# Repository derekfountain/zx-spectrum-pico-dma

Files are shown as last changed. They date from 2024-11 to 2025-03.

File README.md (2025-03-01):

# zx-spectrum-pico-dma

The Z80 CPU inside the ZX Spectrum is capable of DMA transfers. i.e. an external
device can take control of the buses and directly read and write the Spectrum's
memory.

To the best of my knowledge, no interface from the Spectrum's commercial era ever
took advantage of this feature, probably because it's a rather fussy thing to
work with. I wondered if it was possible for a modern microcontroller to do it.
Hence this project.

Answer: yes, it can.

# Two implementations

My first attempt at getting this DMA idea to work used my ZX Diagnostics Board
as a test platform. The fundamental problem is that an RP2040-based Pico doesn't
have enough GPIOs to do this sort of task. (It has 26, the Z80's address and data
buses immediately account for 24 of them.) I got it to work, but synchronising
the dual Picos was too slow and fussy. I eventually gave up on that and designed
a new Spectrum interface based on the RP2350B microcontroller.

The dual Pico approach is documented towards the end of this page. It's probably
not of much interest to most people. The RP2350B implementation is the more
interesting one. So let's start there.

## RP2350B Implementation

My second attempt at getting this to work involved a Raspberry Pi RP2350B microcontroller,
which has 48 GPIOs. Unlike the original RP2040, this is plenty enough for this sort of
project. I used a [Pimoroni Stamp XL](https://shop.pimoroni.com/products/rp2350-stamp-xl?variant=53521688002939).

### The Hardware

I designed a board and had it made up. It looks like this:

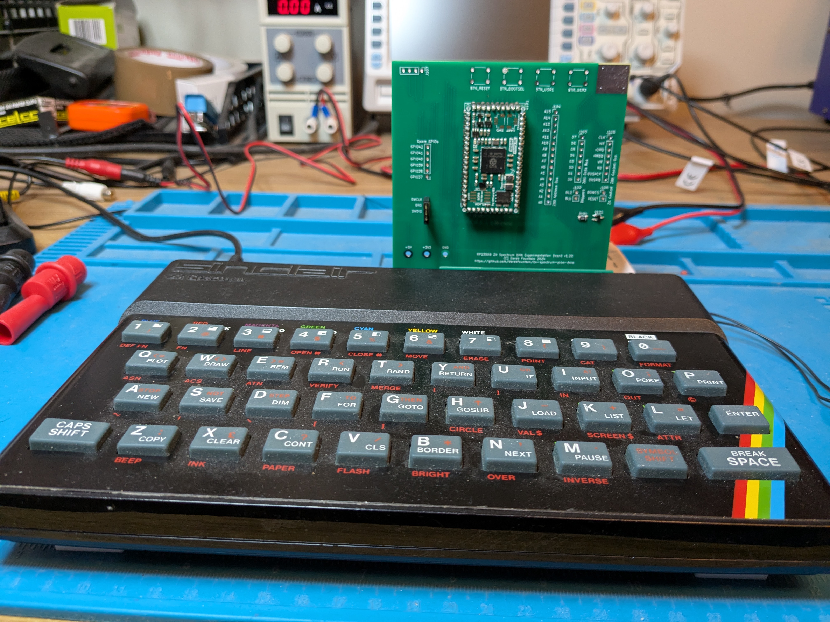
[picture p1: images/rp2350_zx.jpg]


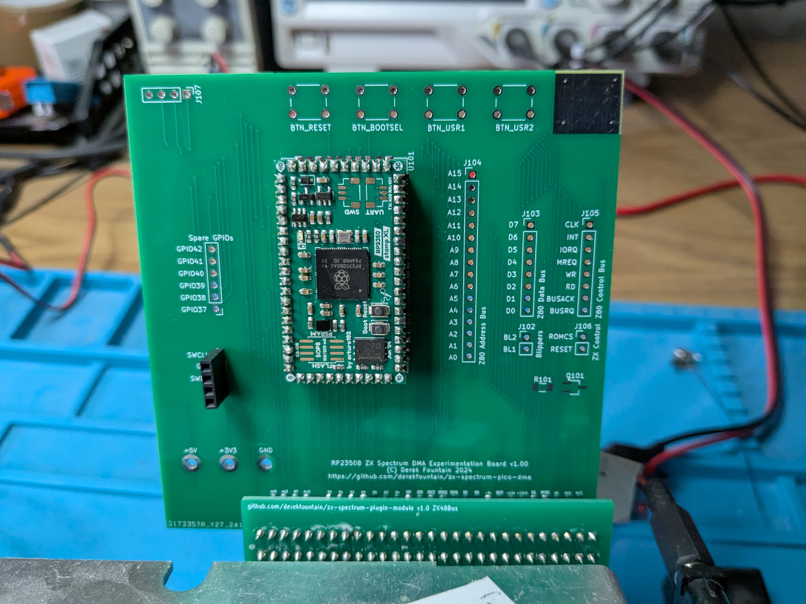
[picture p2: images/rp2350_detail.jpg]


It's very simple, the Stamp XL runs off 5V so doesn't need any extra circuitry other
than a transistor to control the Z80's RESET line.

The RP2350 can handle the Spectrum's 5V signals as direct inputs to the GPIOs, so
the design is just to link pretty much everything on the Spectrum's rear edge connector
to a GPIO pin. The rest can be done in software.

### The Contention Problem

One of the primary reasons this DMA approach has rarely, if ever, been seen on a
Spectrum interface is the contention problem. The Spectrum's display is
generated by the ULA based on data it finds in the lower 16K of RAM. In order
to do that the ULA needs to be able to read that data from the 4116 DRAM
chips. But those chips are single ported, which means if the ULA and Z80 try
to read and/or write them simultaneously contention will happen, the ULA 
will get delayed or corrupted data, and the screen display will glitch.

The solution to this in the Spectrum circuitry is to have the ULA stop the
Z80's clock while the ULA is reading the screen memory. This solution would
also be required of any circuit which uses DMA to read or write the screen
memory. That is, if an external device takes control of the buses in order
to read or write to the screen memory, that device needs to stay clear of
the ULA's screen memory accesses otherwise contention becomes a problem.

### Timings

To do a DMA transfer into screen memory (0x4000 to 0x5AFF inclusive) it needs
to be timed precisely with the Spectrum's ULA hardware. The Spectrum hardware
in this area is simple and limited. The ULA emits a signal named INT
(because it's connected to the Z80's interrupt line) every 20ms. It does so when
the hardware is about to start drawing the screen and the TV raster is at the
top left corner.

So yes, that's simple, but it's also limited, because that's the only timing
signal the Spectrum emits. I have to work with that.

### Challenge 1 - Get it working

The initial challenge, then, is to get DMA working on the Spectrum. The aim here
is to write a single byte of data into the top left corner of the screen, with
everything else remaining stable and glitch free.

I'm going to put a dotted line - value 0x55 - in location 0x4000, so 4 little
dots appear in the corner.

### Approach

The approach used for this experimentation is as follows:

* RP2350 will raise a bus request, then wait for the Z80 to yield the buses and
respond with bus acknowledge
* RP2350 will put the address 0x4000 on the address bus
* RP2350 will put the value 0x55 on the data bus
* RP2350 will drive the signal lines in sequence to force a memory write
* RP2350 will then release the bus request signal and the Z80 can go back to
doing whatever it was doing

Compared the dual-Pico approach (scroll down if you want to know) this is pretty
straightforward, and works fine.

The key point is with the timing: this is going to happen while the ULA is
drawing the top border. Contention doesn't happen when the ULA is in 
"border time", only when the ULA is drawing the data part of the screen.
So if the DMA work can be done during border time there's no need to worry
about contention.

The other question is how long the buses need to be driven for. The first version
of my software controlled the signals with the same timing the Z80 uses. It
watched the CLK signal and responded to rising and falling clocks exactly as the
Z80 does (according to the timing diagrams in the Z80 manual). But that's not
necessary. Signals on the buses and control lines (like /MREQ and /WR) get to the
4116 DRAM chips via the Spectrum's ULA and multiplexers which pass the signals
in small numbers of nanoseconds. The 4116s themselves are the slow points, being
rated at completing a read or write in 150ns. It turns out that adding a delay
of 35 RP2350 "NOP" instructions between the /WR signal going active and inactive
is the minium requirement for successful writes. On a 150MHz RP2350 35 of the
single-cycle "NOP" instructions complete in 233ns, which seems a slower than it
needs to be. I need to investigate this. My test Spectrum for this project has been
one with a static RAM-based lower memory module, so it's hard to draw conclusions
from this hardware.

### Result

There's no point is trying to do this on an emulator, so screenshots are photos
from a real Spectrum screen.

Here's the result of the single byte write:

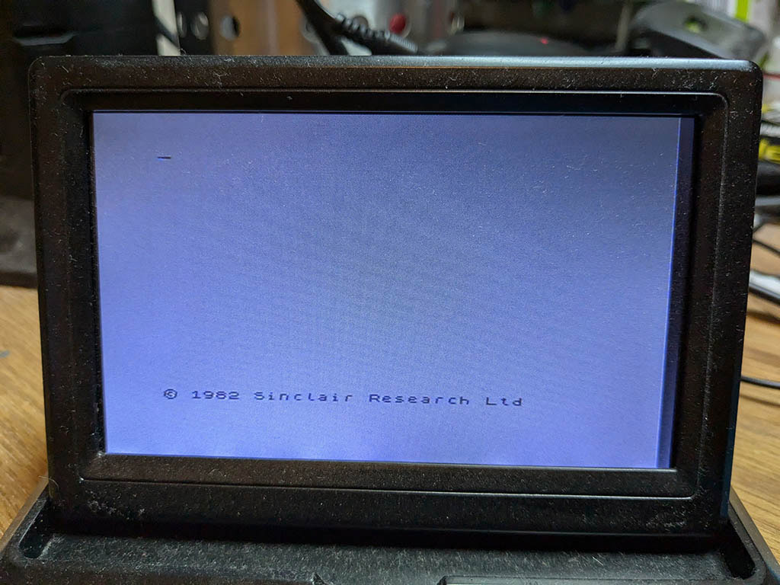
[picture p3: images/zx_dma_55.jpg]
0x55 in screen


It's fuzzy and blurry, but, take my word for it, it does show what it should:
that splat in the in the top left corner is actually 4 individual dots. It sits
there permanently. Tapping ENTER clears the screen, but the dots flicker and
reappear immediately. They're being replaced every 20ms.

There's no way to stop this from the Z80 end. The BUSREQ/BUSACK mechanism on
the Z80 is highest priority, higher than NMI, even. If I do something on the
Spectrum which disables interrupts, the dots appear there anyway. The BEEP
command still plays a note, but it's a bit "buzzy."

### Transferring a Screenful of Data

The question that needed answering here was whether the DMA transfer would be fast
enough to move a whole ZX Spectrum display frame of data (6,912 bytes) from the RP2350
into the Spectrum's display memory in the time it takes the ULA to draw the top border.
This is where the dual-Pico approach (described below) had failed, and which I needed
to work if this DMA idea was going to be useful.

I boosted the transfer from 1 byte to 6,912 bytes and looked at the timings on the
oscilloscope. It looks like this:

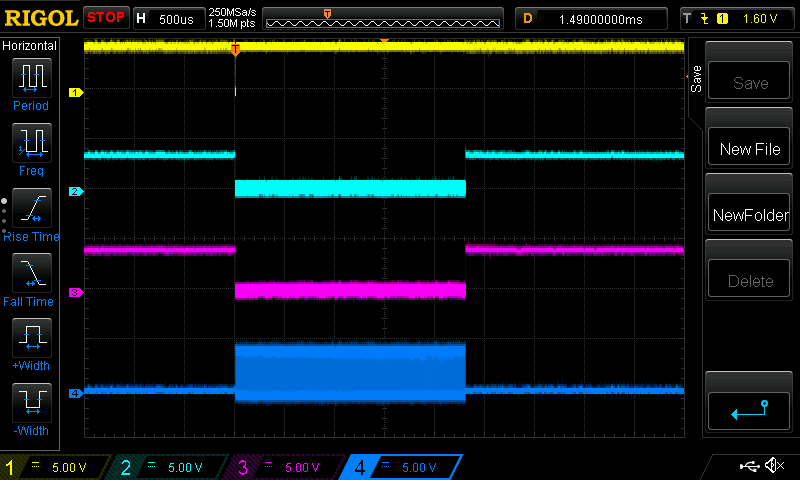
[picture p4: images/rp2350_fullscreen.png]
Full screen trace


The blip on the yellow line is the ULA's INT signal indicating a new frame is starting.
The cyan line is the BUSREQ signal as the RP2350 requests the Z80's bus, and the purple
line is the Z80's BUSACK signal showing the Z80 has yielded the bus. The dark blue line
is a test signal which the RP2350 is waggling as each of the 6,912 bytes is fed to the
Spectrum's lower memory. The entire duration of the transfer is about 2.3ms, which is
easily inside the 4.1ms the ULA takes to draw the top border.

## Success!

This is excellent news! Using the RP2350, with all its GPIOs, means it's easily possible
to DMA transfer a whole screen of data, flicker and contention free, from the 
microcontroller into the Spectrum inside the time it takes to draw the top border.

The next step will be to utilise this DMA transfer as part of a ZX co-processor. I have
this vague idea that a RP2350 can be used to do the sorts of things the ZX Spectrum finds
very hard, such as full screen scrolling. That's a different project, but in the meantime
I added a 50-frames-per-second, full screen scroll routine into the RP2350 code, just to
show it's possible. Here's a terribly wobbly (phone in one hand, typing on the rubber keys
with the other) animated GIF showing that scroll working:

Animated GIF

## ZX Diagnostics Board Implementation

**TLDR: I got DMA working via a variation of my ZX Diagnostics Board which consists
of 2 Raspberry Pi Picos. But it was slow: with one Pico controlling the address bus,
and the other Pico controlling the data and control buses, a lot of time was wasted
due to the 2 Picos needing to keep sync with one another. So although it worked, it
wasn't really a usable solution. What follows is for the enthusiastic reader only.**

My first attempt at getting this working used my [ZX Diagnostics Board](https://github.com/derekfountain/zx-spectrum-diagnostics) project
as a testbed. What follows is the write up of what I did and how far I got.
Might be useful to someone, for something.

The Pico software which was working at the end of this experimentation is
tagged as v0.2.

### The Hardware

The hardware I used for this experimentation is my [ZX Diagnostics Board](https://github.com/derekfountain/zx-spectrum-diagnostics).
This board was designed to be flexible. It exposes on headers all the signals
from the Z80 (that are on the Spectrum's rear edge connector), which makes it
ideal for this sort of hardware hackery.

The main problem with doing retro-computing projects with the Pico is the limited
number of GPIOs: 26. To interface to an 8-bit micro you need to connect
GPIOs to 16 bits of address bus and 8 bits of data bus, which is 24, plus whatever
other control bus signals you need, plus user interface buttons and other things.
26 GPIOs isn't enough.

My diagnostics board interface has 2 Raspberry Pi Picos. One Pico is set up with
GPIOs connected to the data bus and several of the Z80 control bus signals, the
other Pico is set up with GPIOs connected to the 16 bits of address bus. A bit of
to and fro is required to keep them in sync, and it isn't ideal, but it does work.

I had to modify the diagnostics board slightly because when I designed it 
BUSREQ and BUSACK where not signals I connected to either Pico. So I soldered an extra
couple of wires:

* Pico 1 GPIO 16 connected to BUSREQ
* Pico 1 GPIO 17 connected to BUSACK

These Z80 signals were also wired to Pico 2 GPIO 26 and 28 respectively.

The other signals required here are IORQ, MREQ, RD and WR. These were already
connected up to Pico 1.

### The Contention Problem

One of the primary reasons this approach has rarely, if ever, been seen on a
Spectrum interface is the contention problem. The Spectrum's display is
generated by the ULA based on data it finds in the lower 16K of RAM. In order
to do that the ULA needs to be able to read that data from the 4116 DRAM
chips. But those chips are single ported, which means if the ULA and Z80 try
to read and/or write them simultaneously contention will happen, the ULA 
will get delayed or corrupted data, and the screen display will glitch.

The solution to this in the Spectrum circuitry is to have the ULA stop the
Z80's clock while the ULA is reading the screen memory. This solution would
also be required of any circuit which uses DMA to read or write the screen
memory. That is, if an external device takes control of the buses in order
to read or write to the screen memory, that device needs to stay clear of
the ULA's screen memory accesses otherwise contention becomes a problem.

### Timings

To do a DMA transfer into screen memory (0x4000 to 0x5AFF inclusive) it needs
to be timed precisely with the Spectrum's ULA hardware. The Spectrum hardware
in this area is simple and limited. The ULA emits a signal named INT
(because it's connected to the Z80's interrupt line) every 20ms. It does so when
the hardware is about to start drawing the screen and the TV raster is at the
top left corner.

So yes, that's simple, but it's also limited, because that's the only timing
signal the Spectrum emits. I have to work with that.

### Challenge 1 - Get it working

The initial challenge, then, is to get DMA working on the Spectrum. The aim here
is to write a single byte of data into the top left corner of the screen, with
everything else remaining stable and glitch free.

I'm going to put a dotted line - value 0x55 - in location 0x4000, so 4 little
dots appear in the corner.

### Approach

The approach used for this experimentation is as follows:

* Pico1 will raise a bus request, then wait for the Z80 to yield the buses and
respond with bus acknowledge
* Pico1 will tell Pico2 - which controls the address bus - to put the address
0x4000 on the address bus
* Pico1 will put the value 0x55 on the data bus
* Pico1 will drive the signal lines in sequence to force a memory write
* When the byte is written, Pico1 will tell Pico2 to stop driving the address
bus, and will itself stop driving the data and control bus lines
* Pico1 will then release the bus request signal and the Z80 can go back to
doing whatever it was doing

The key point is with the timing: this is going to happen while the ULA is
drawing the top border. Contention doesn't happen when the ULA is in 
"border time", only when the ULA is drawing the data part of the screen.
So if the DMA work can be done during border time there's no need to worry
about contention.

The other question is how long the buses need to be driven for. The first version
of my software controlled the signals with the same timing the Z80 uses. It
watched the CLK signal and responded to rising and falling clocks exactly as the
Z80 does (according to the timing diagrams in the Z80 manual). But that's not
necessary. Signals on the buses and control lines (like /MREQ and /WR) get to the
4116 DRAM chips via the Spectrum's ULA and multiplexers which pass the signals
in small numbers of nanoseconds. The 4116s themselves are the slow points, being
rated at completing a read or write in 150ns. It turns out that adding a delay
of 19 RP2040 "NOP" instructions between the /WR signal going active and inactive
is the minium requirement for successful writes. On a 125MHz RP2040 19 of the
single-cycle "NOP" instructions complete in 152ns, which seems to add up.

### Result

There's no point is trying to do this on an emulator, so screenshots are photos
from a real Spectrum screen.

Here's the result of the single byte write:

0x55 in screen

It's fuzzy and blurry, but, take my word for it, it does show what it should:
that splat in the in the top left corner is actually 4 individual dots. It sits
there permanently. Tapping ENTER clears the screen, but the dots flicker and
reappear immediately. They're being replaced every 20ms.

There's no way to stop this from the Z80 end. The BUSREQ/BUSACK mechanism on
the Z80 is highest priority, higher than NMI, even. If I do something on the
Spectrum which disables interrupts, the dots appear there anyway. The BEEP
command still plays a note, but it's a bit "buzzy."

### Signals Analysis

Here's the trace from the oscilloscope:

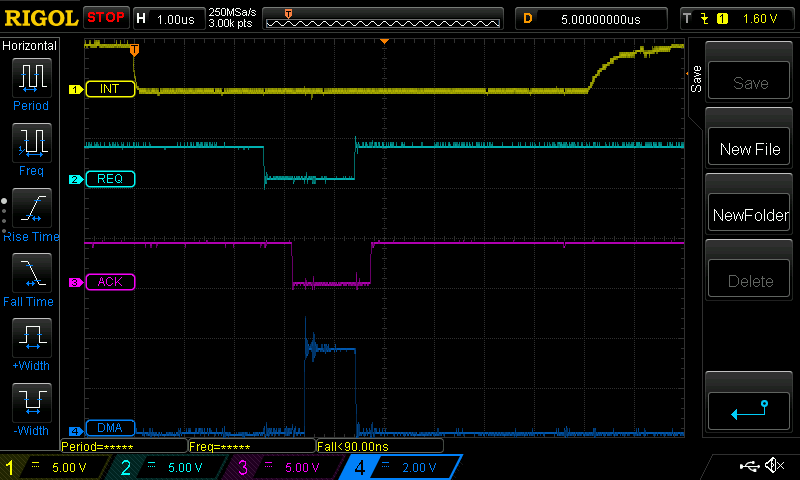
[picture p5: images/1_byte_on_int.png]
1 byte DMA trace


Yellow is the ULA's INT signal, which is pulled low every 20ms. The RP2040 on the
Pico is programmed with a hardware interrupt when that line goes low. The handler
function asserts the BUSREQ "bus request" signal, which is the light blue line.
BUSREQ goes low approximately 2.5 microseconds after INT goes low, that being the
time it takes for the RP2040 to respond to a GPIO interrupt.

The RP2040 code spins looking for BUSACK "bus acknowledge" to go low. There is a
variable length pause while the Z80 finishes the instruction it's running, and then
it pulls BUSACK low. That's the purple line. In the shown example, BUSACK goes low
about 600ns after BUSREQ went low, but this varies. The purple line flickers on
the 'scope.

When the BUSACK goes low the DMA process takes place. The dark blue line shows a high
pulse while the DMA is running. It takes just about 1uS to drive a transfer of one
byte to the Spectrum's memory. This includes the wasteful but necessary synchronisation
with the other Pico which drives the address bus.

As soon as the DMA is complete (blue line falling) the BUSREQ line is released
(light blue line rising). The Z80 retakes control (purple line rising as it turns
off the BUSACK signal) and the process is complete. End of DMA to the Z80 having
control again is about 150ns.

The Z80 "loses" the period of the purple line being low, which is about 1.6uS.

### Challenge 2 - More data

Proving a single byte can be written into Spectrum memory is gratifying, but not really
very useful. Next step is to try writing more data. Let's try 2KB. This requires
advancing the value on the address bus with each byte written. Here's the screen,
again a bit fuzzy, but correctly showing what it should:

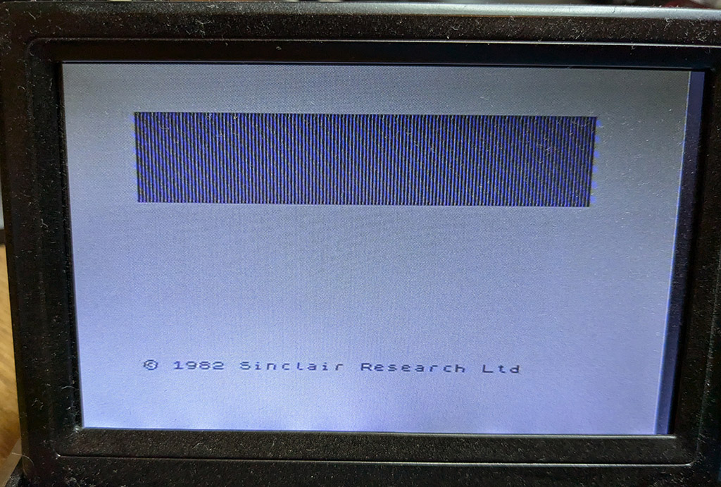
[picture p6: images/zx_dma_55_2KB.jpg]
0x55 in 2KB screen


That pattern is permanent, and since it takes a lot longer to transfer in than the
single byte example, the BEEP is a lot buzzier. Some games, presumably those that
don't read back their screen data, still work. Jetpac, for example, still runs quite
happily even though you can't see what you're doing.

The trace from the oscilloscope:

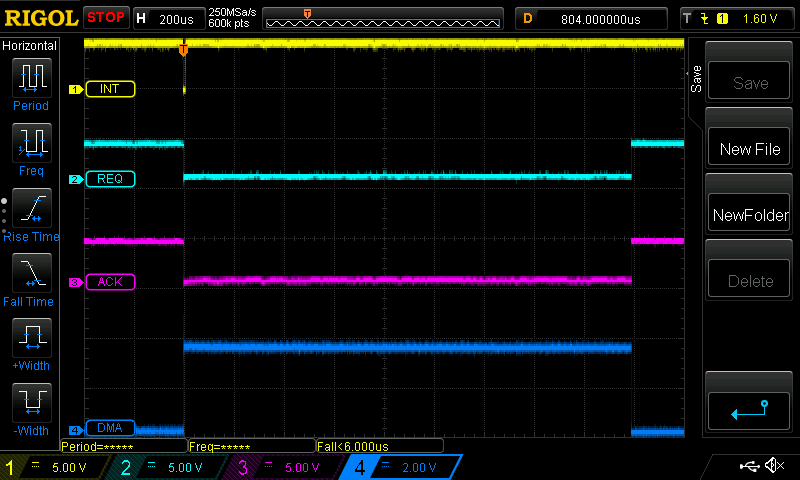
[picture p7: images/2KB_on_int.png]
2KB DMA trace


This all looks OK, but a problem is starting to appear. It takes the ULA 224 Z80 T-states
to draw a single line of the screen, and the top border is 64 lines high. So  Spectrum "top
border time" is 64 line times, which is 14,336 T states. A T is 1/3,500,000 of a second so
top border time is 0.004096 of a second, or a smidge over 4ms. The oscilloscope trace shows
the DMA time for 2048 bytes (dark blue line) to be just about 1,800uS, or 1.8ms. That's to
DMA one third of a Spectrum screen. A full screen will take 5.4ms, not including the time
taken to transfer the attributes data which is another 768 bytes (32x24 bytes).

I put a trace pulse in the code which drives the address bus:
 
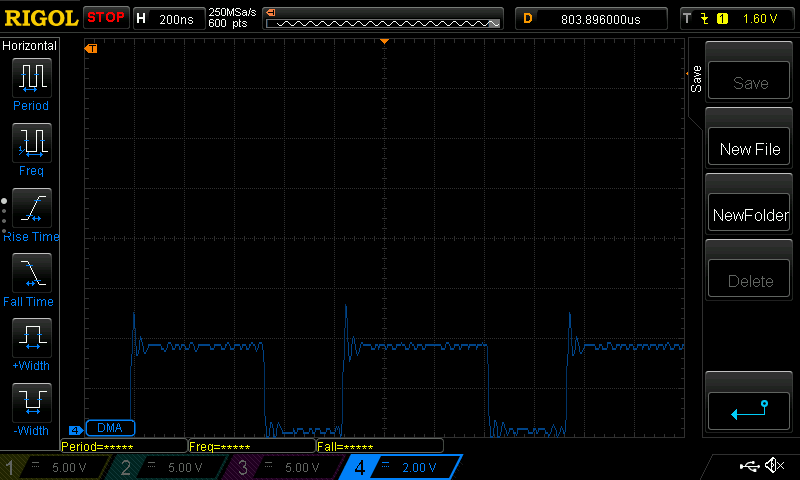
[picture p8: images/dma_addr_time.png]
Addr time trace


This line goes high at the point the required address is loaded onto the Z80's address
bus, then goes low again when the address bus is relinquished. It takes about 500ns,
so that's the time for writing one byte. On top of that, there's quite a bit of overhead as
the Picos signal and synchronise with each other, all of which could be removed if I can use a
single microcontroller with enough GPIOs to do everything itself. But I don't have one
of those, and there's no way to avoid the synchronisation at the moment.

This is disappointing. DMA can only really be done in border time, to avoid contention. (I
saw plenty of contention while I was experimenting with this. The screen glitches all over
the place.) I was hoping to be able to do full screen scrolling in the RP2040, for example,
but clearly if the screen can't be quickly transferred back into the Spectrum after processing
then it's not much use.

I figured it might be possible to interweave the DMA with the CPU's CLK signal. The CLK is
generated by the ULA, so when the CLK signal goes flat that means the ULA is accessing
RAM. But that means somehow accessing the CLK such that when it stops pulsing the RP2040
stops the DMA. It might be possible to do that? Perhaps a PIO watching the CLK signal
and indicating to the core when the CLK stops? I didn't try it but it might work.

### Challenge 3 - A Screenful

Next step is to try transferring a full screen of data into the Spectrum. This is the
underlying requirement. If an RP2040 is to be used to do full screen scrolling or other such
things it needs to be able to transfer the results back into the Spectrum at 50fps. If it
can't there's only so much point in doing it. You might as well do the job on the Spectrum.

So this next experiment does what the previous ones do: transfer a block of data into the
Spectrum at the point of the ULA's INTerrupt, when the ULA is drawing the top border. The
data block for a full screen is 6,912 byte - 6,144 for the graphics, plus 768 for the 
attributes.

Here's how the result looks:

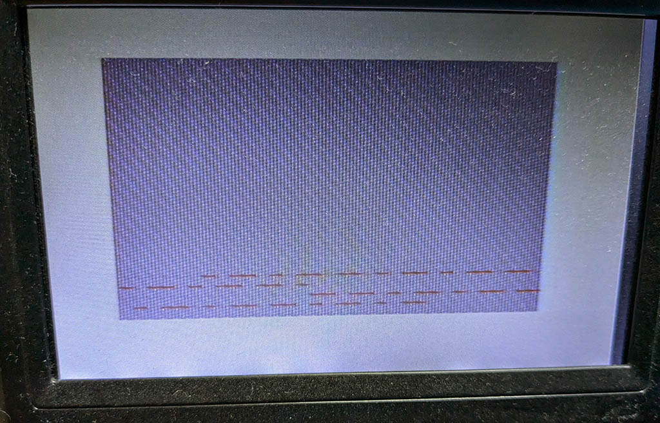
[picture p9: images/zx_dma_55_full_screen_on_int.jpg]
Full screen DMA trace


The screen fills as expected, but there's shimmering and glitching, and the Spectrum hangs.

The oscilloscope trace looks like this:

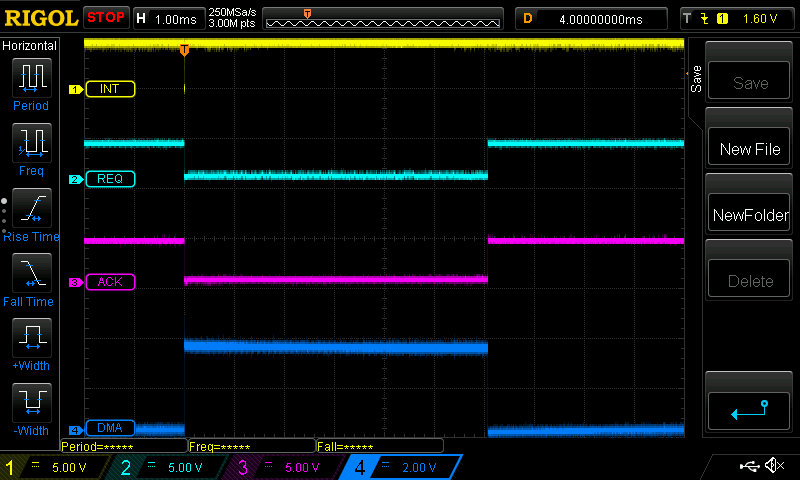
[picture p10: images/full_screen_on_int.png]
Full screen trace


This is at 1ms per division, the entire DMA trace takes just over 6ms. Top border time is
4ms, this is causing contention, hence the flickering.

I think the Spectrum is hanging because the Z80 is getting incorrect data from the lower
RAM, which is where it stores system information. The contention doesn't just affect the
screen memory, it affects all the lower 16K. I'm not entirely sure what's going on with this
hangup to be honest, but it doesn't really matter. A full screen DMA isn't possible in top
border time.

#### Try Bottom Border Time

The Spectrum's border is in two pieces, top and bottom, separated by the screen image of course.
If I can start the DMA at the point the ULA starts to draw the bottom border (i.e. just as it's
finished drawing line 192 of the screen itself) then I get bottom border time, followed by top
border time, before the ULA wants to access the RAM again (in order for it to start drawing the
top line of the screen).

Lower border is 56 lines at 224Ts per line, which is 12,544 Ts. On the 3.5MHz Z80 12,544 T-states
takes 0.003584 seconds, or 3.584ms. So if I can time it perfectly, I get 3.584ms of bottom
border time, followed by 4.096ms of top border time, to complete the DMA without causing
contention. That's 7.68ms, which should be enough to complete the full screen DMA which takes
just over 6ms.

The problem is that there's no timing signal or indication that the ULA has completed drawing the
data area and is about to start drawing the bottom border. The only option is to do it on a timer.
To hit the start of lower border time from the moment INT fires, I need 64 lines of top border,
plus 192 lines of screen, That's 228 lines from INT to the start of the lower border. At 224Ts per
line, 228 lines is 64,512 Ts. That's 18.432ms.

The approach here is to start a timer for 18,432uS in the INT handler, then go back to sleep. The
DMA actually happens when the second timer expires:

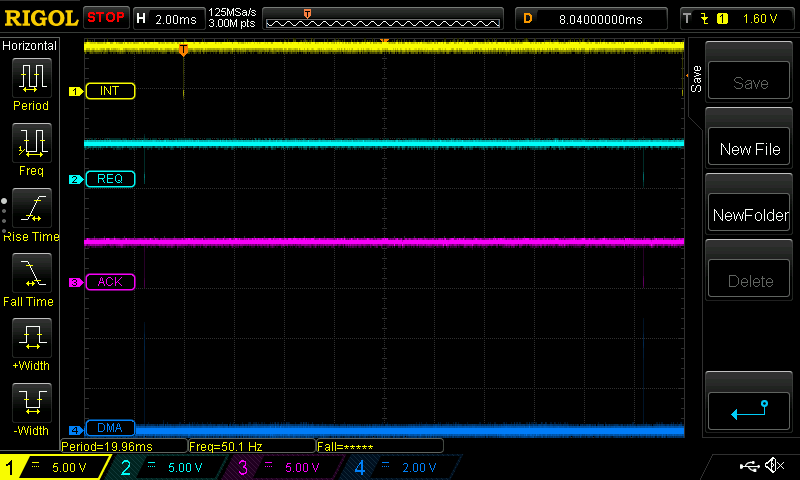
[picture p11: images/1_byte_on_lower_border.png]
1 byte on lower border trace


Here, yellow shows is the INT signal, which is the point when the 18,432uS timer is started. Light
blue shows the BUSREQ signal, which is the start of the DMA process. The 'scope's cursor shows the
time difference between the two:

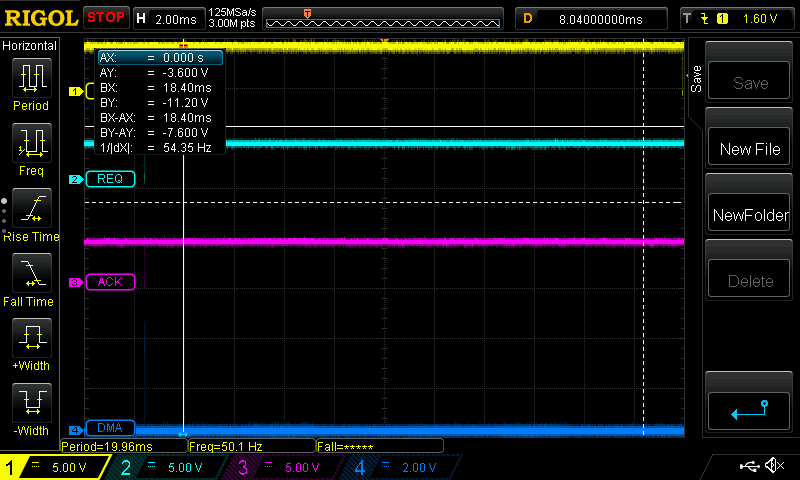
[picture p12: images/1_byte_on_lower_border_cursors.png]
1 byte on lower border trace


The gap is 18.4ms, which looks right. I'm hoping the 0.032ms offset is a measuring error.

The above images are based on a single byte DMA, which worked. But something very odd started
happening in the RP2040 when I made the transfer larger. It seems the Pico SDK wouldn't set up the
next alarm call function until the current one finished executing. So the first INT would arrive
and its handler would set the 18.4ms timer running. When that expired the DMA would start. But with
a large DMA, the transfer would still be running when the next INT arrived. With the alarm timer
still running and DMAing bytes to the Spectrum, either the INT handler didn't run, or it wouldn't
set up the alarm handler correctly. After a lot of messing about I found that doing the DMA
transfer from the second core of the RP2040 made the problem go away and the screen filled as
expected:

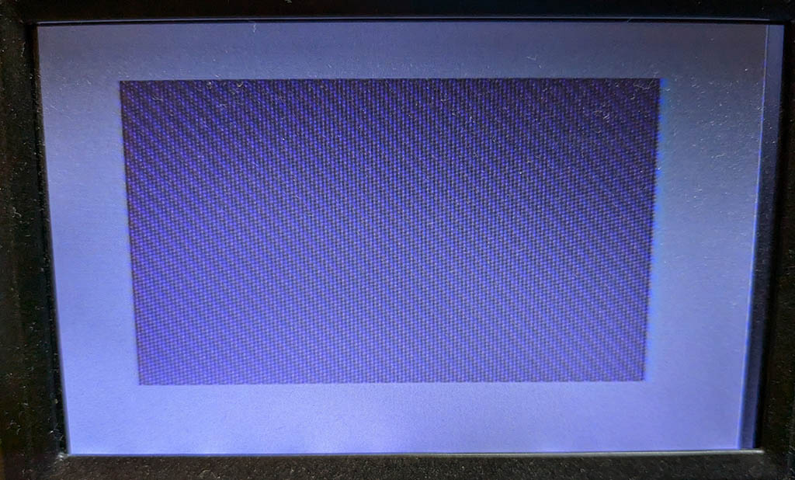
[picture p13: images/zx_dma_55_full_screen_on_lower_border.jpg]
Full screen DMA trace


Here's the oscilloscope trace:

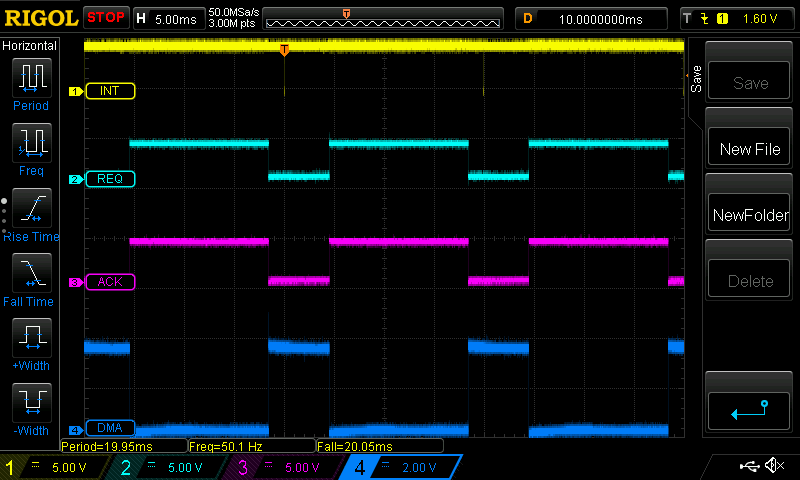
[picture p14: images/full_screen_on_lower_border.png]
full screen on lower border trace


The first INT is where the orange trigger cursor is on the yellow line. That causes a handler
to run which sets up an alarm to call the DMA function 18.4ms seconds later. The DMA function
for that INT is the next one on the light blue line - i.e. not the one directly below the INT,
but the one nearly 4 divisions later, to the right. As you can see, the next INT arrives during
the DMA process, which sets up the next alarm while the current one finishes, and so on.

## Fail

With the dual core hack in place, this worked! Hurrah! Only it didn't, because although the DMA
worked correctly, and at just about spot on 6.0ms was plenty quick enough to be inside the 7.68ms
dual borders time, the Spectrum hanged every time. It took me an age to work out why, but it's
obvious when you know: the INT signal is being generated correctly by the ULA, and the Pico is
responding to it correctly, but because the bus request is active when the next INT comes in
the Z80 (which is effectively sitting suspended) doesn't see it. So the Spectrum's not getting to
run its interrupt routine which does all sort of useful stuff like reading the keyboard.

It might still be possible to make this work. Some of the DMA transfer could be done in lower
border time, and as long as that was finished and the BUSREQ removed by the time the next INT
arrived, it might then be possible to do the rest of the DMA transfer in top border time. i.e. do it
in two portions. But for BASIC to work properly the top border transfer needs to be well clear of
the Spectrum ROM's interrupt handler routine. It's messy and fiddly and not really the solution
I'm after.

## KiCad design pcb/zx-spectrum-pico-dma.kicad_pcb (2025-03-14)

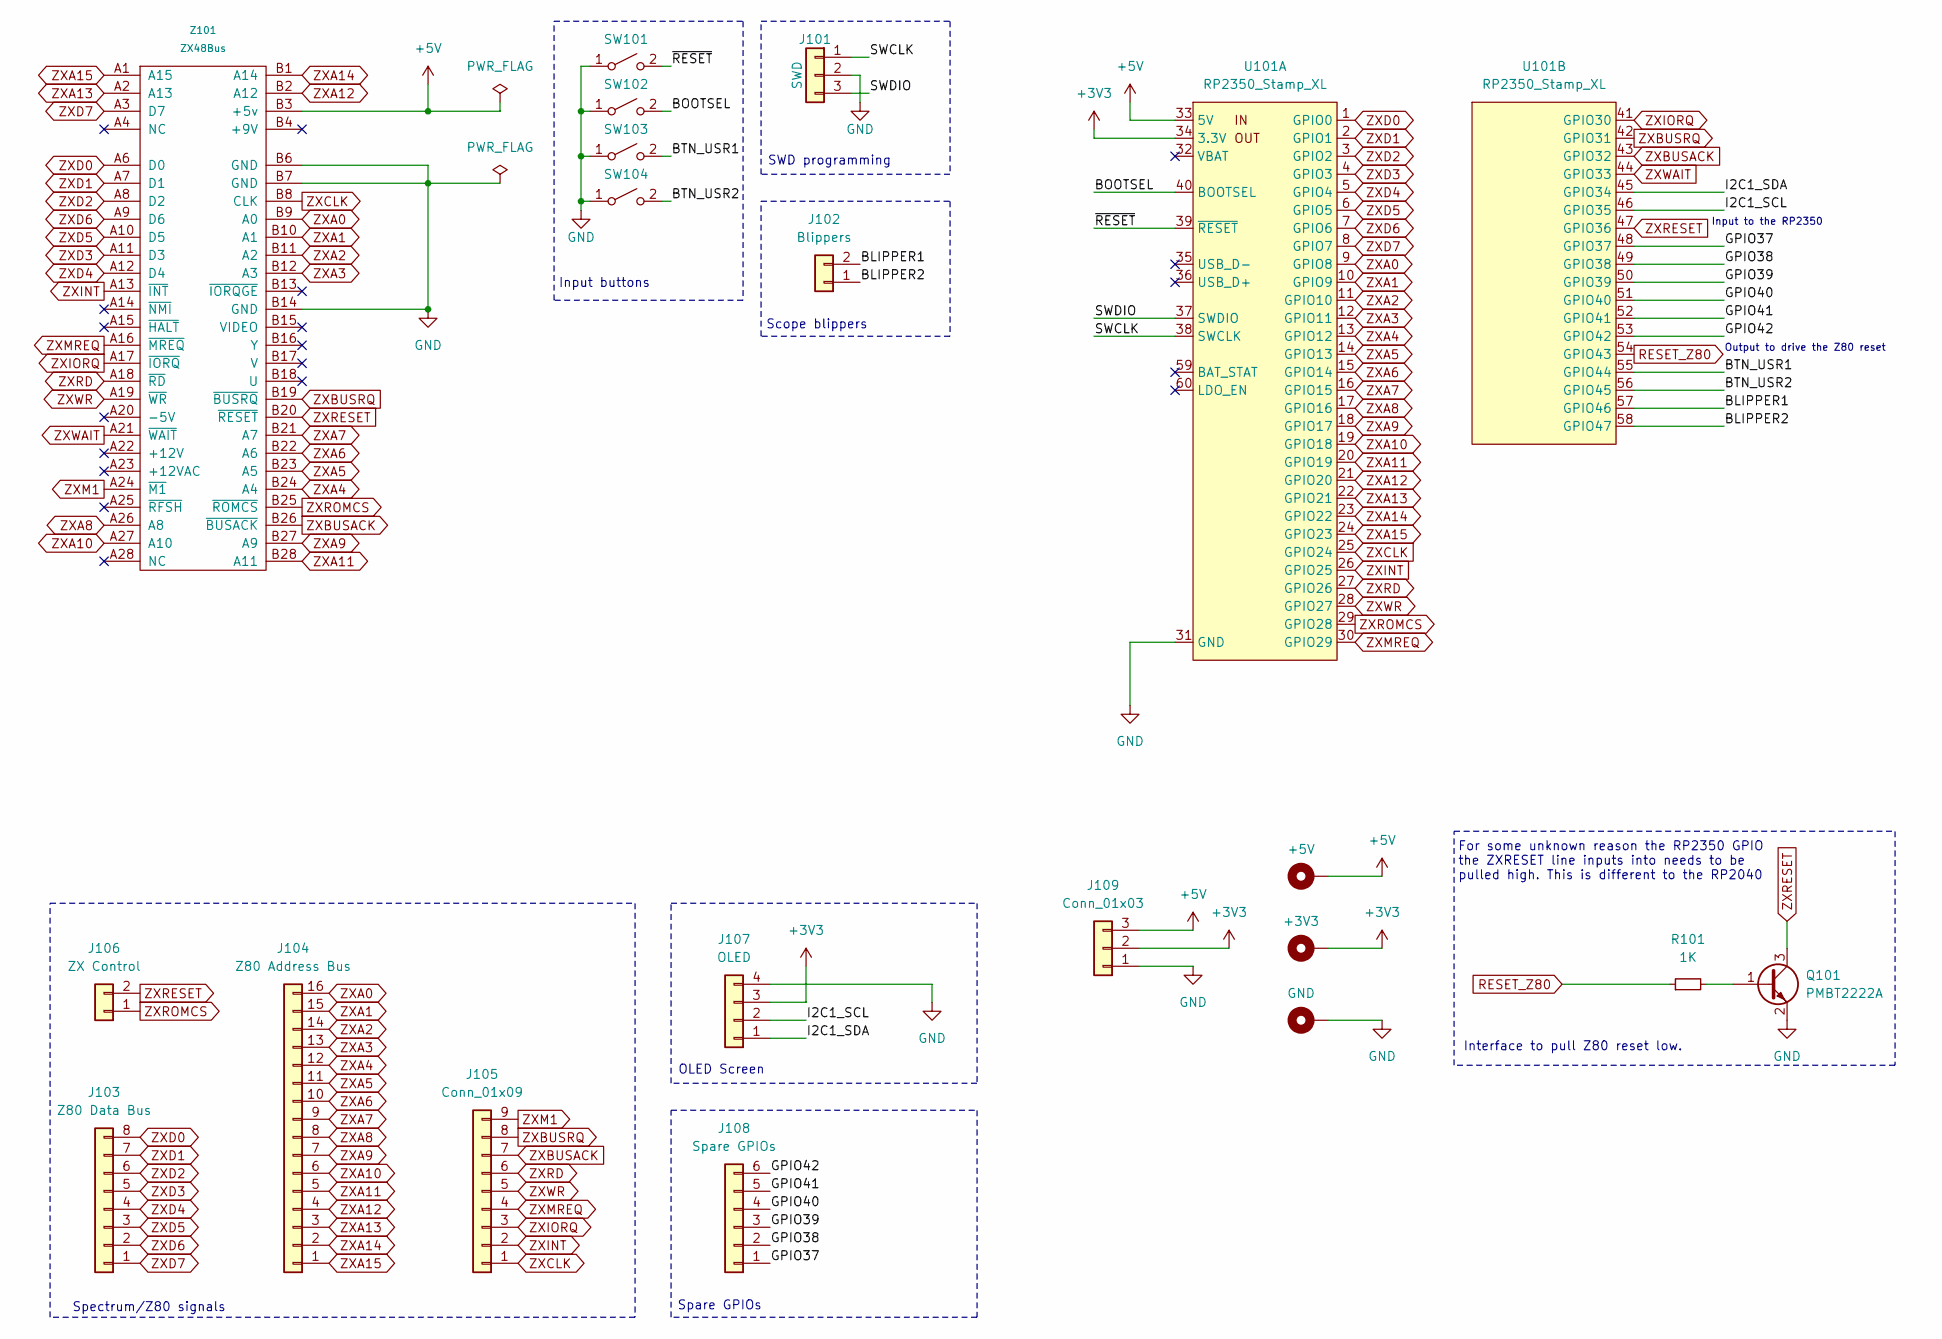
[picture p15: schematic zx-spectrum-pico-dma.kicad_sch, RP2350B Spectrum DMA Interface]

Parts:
H101: +5V; MountingHole_2.2mm_M2_Pad
H102: +3V3; MountingHole_2.2mm_M2_Pad
H103: GND; MountingHole_2.2mm_M2_Pad
J101: SWD; PinHeader_1x03_P2.54mm_Vertical; LCSC C7433424
J102: Blippers; PinHeader_1x02_P2.54mm_Vertical
J103: Z80 Data Bus; PinHeader_1x08_P2.54mm_Vertical
J104: Z80 Address Bus; PinHeader_1x16_P2.54mm_Vertical
J105: Conn_01x09; PinHeader_1x09_P2.54mm_Vertical
J106: ZX Control; PinHeader_1x02_P2.54mm_Vertical
J107: OLED; PinHeader_1x04_P2.54mm_Vertical
J108: Spare GPIOs; PinHeader_1x06_P2.54mm_Vertical
J109: Conn_01x03; PinHeader_1x03_P2.54mm_Vertical
Q101: PMBT2222A; TSOT-23_HandSoldering
R101: 1K; R_1206_3216Metric_Pad1.30x1.75mm_HandSolder
SW101: BTN_RESET; SW_PUSH_6mm_H4.3mm; LCSC C561514
SW102: BTN_BOOTSEL; SW_PUSH_6mm_H4.3mm; LCSC C561514
SW103: BTN_USR1; SW_PUSH_6mm_H4.3mm; LCSC C561514
SW104: BTN_USR2; SW_PUSH_6mm_H4.3mm; LCSC C561514
U101: RP2350_Stamp_XL; RP2xxx_Stamp_XL_THT
Z101: ZX48Bus; Spectrum_Edge_Connector

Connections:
+3V3: H102.1, J107.3, J109.2, U101.34 (3.3V)
+5V: H101.1, J109.3, U101.33 (5V), Z101.B3 (+5v)
/BLIPPER1: J102.2, U101.57 (GPIO46)
/BLIPPER2: J102.1, U101.58 (GPIO47)
/BOOTSEL: SW102.2 (B), U101.40 (BOOTSEL)
/BTN_USR1: SW103.2 (B), U101.55 (GPIO44)
/BTN_USR2: SW104.2 (B), U101.56 (GPIO45)
/GPIO37: J108.1, U101.48 (GPIO37)
/GPIO38: J108.2, U101.49 (GPIO38)
/GPIO39: J108.3, U101.50 (GPIO39)
/GPIO40: J108.4, U101.51 (GPIO40)
/GPIO41: J108.5, U101.52 (GPIO41)
/GPIO42: J108.6, U101.53 (GPIO42)
/I2C1_SCL: J107.2, U101.46 (GPIO35)
/I2C1_SDA: J107.1, U101.45 (GPIO34)
/SWCLK: J101.1, U101.38 (SWCLK)
/SWDIO: J101.3, U101.37 (SWDIO)
/~RESET: SW101.2 (B), U101.39 (~RESET)
GND: H103.1, J101.2, J107.4, J109.1, Q101.2 (E), SW101.1 (A), SW102.1 (A), SW103.1 (A), SW104.1 (A), U101.31 (GND), Z101.B6 (GND), Z101.B7 (GND), Z101.B14 (GND)
unnamed: Q101.1 (B), R101.2
RESET_Z80: R101.1, U101.54 (GPIO43)
ZXA0: J104.16, U101.9 (GPIO8), Z101.B9 (A0)
ZXA1: J104.15, U101.10 (GPIO9), Z101.B10 (A1)
ZXA2: J104.14, U101.11 (GPIO10), Z101.B11 (A2)
ZXA3: J104.13, U101.12 (GPIO11), Z101.B12 (A3)
ZXA4: J104.12, U101.13 (GPIO12), Z101.B24 (A4)
ZXA5: J104.11, U101.14 (GPIO13), Z101.B23 (A5)
ZXA6: J104.10, U101.15 (GPIO14), Z101.B22 (A6)
ZXA7: J104.9, U101.16 (GPIO15), Z101.B21 (A7)
ZXA8: J104.8, U101.17 (GPIO16), Z101.A26 (A8)
ZXA9: J104.7, U101.18 (GPIO17), Z101.B27 (A9)
ZXA10: J104.6, U101.19 (GPIO18), Z101.A27 (A10)
ZXA11: J104.5, U101.20 (GPIO19), Z101.B28 (A11)
ZXA12: J104.4, U101.21 (GPIO20), Z101.B2 (A12)
ZXA13: J104.3, U101.22 (GPIO21), Z101.A2 (A13)
ZXA14: J104.2, U101.23 (GPIO22), Z101.B1 (A14)
ZXA15: J104.1, U101.24 (GPIO23), Z101.A1 (A15)
ZXBUSACK: J105.7, U101.43 (GPIO32), Z101.B26 (~BUSACK)
ZXBUSRQ: J105.8, U101.42 (GPIO31), Z101.B19 (~BUSRQ)
ZXCLK: J105.1, U101.25 (GPIO24), Z101.B8 (CLK)
ZXD0: J103.8, U101.1 (GPIO0), Z101.A6 (D0)
ZXD1: J103.7, U101.2 (GPIO1), Z101.A7 (D1)
ZXD2: J103.6, U101.3 (GPIO2), Z101.A8 (D2)
ZXD3: J103.5, U101.4 (GPIO3), Z101.A11 (D3)
ZXD4: J103.4, U101.5 (GPIO4), Z101.A12 (D4)
ZXD5: J103.3, U101.6 (GPIO5), Z101.A10 (D5)
ZXD6: J103.2, U101.7 (GPIO6), Z101.A9 (D6)
ZXD7: J103.1, U101.8 (GPIO7), Z101.A3 (D7)
ZXINT: J105.2, U101.26 (GPIO25), Z101.A13 (~INT)
ZXIORQ: J105.3, U101.41 (GPIO30), Z101.A17 (~IORQ)
ZXM1: J105.9, Z101.A24 (~M1)
ZXMREQ: J105.4, U101.30 (GPIO29), Z101.A16 (~MREQ)
ZXRD: J105.6, U101.27 (GPIO26), Z101.A18 (~RD)
ZXRESET: J106.2, Q101.3 (C), U101.47 (GPIO36), Z101.B20 (~RESET)
ZXROMCS: J106.1, U101.29 (GPIO28), Z101.B25 (~ROMCS)
ZXWAIT: U101.44 (GPIO33), Z101.A21 (~WAIT)
ZXWR: J105.5, U101.28 (GPIO27), Z101.A19 (~WR)

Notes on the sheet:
Input to the RP2350
Input buttons
For some unknown reason the RP2350 GPIO the ZXRESET line inputs into needs to be pulled high. This is different to the RP2040
Spare GPIOs
Interface to pull Z80 reset low.
Scope blippers
OLED Screen
Output to drive the Z80 reset
SWD programming
Spectrum/Z80 signals

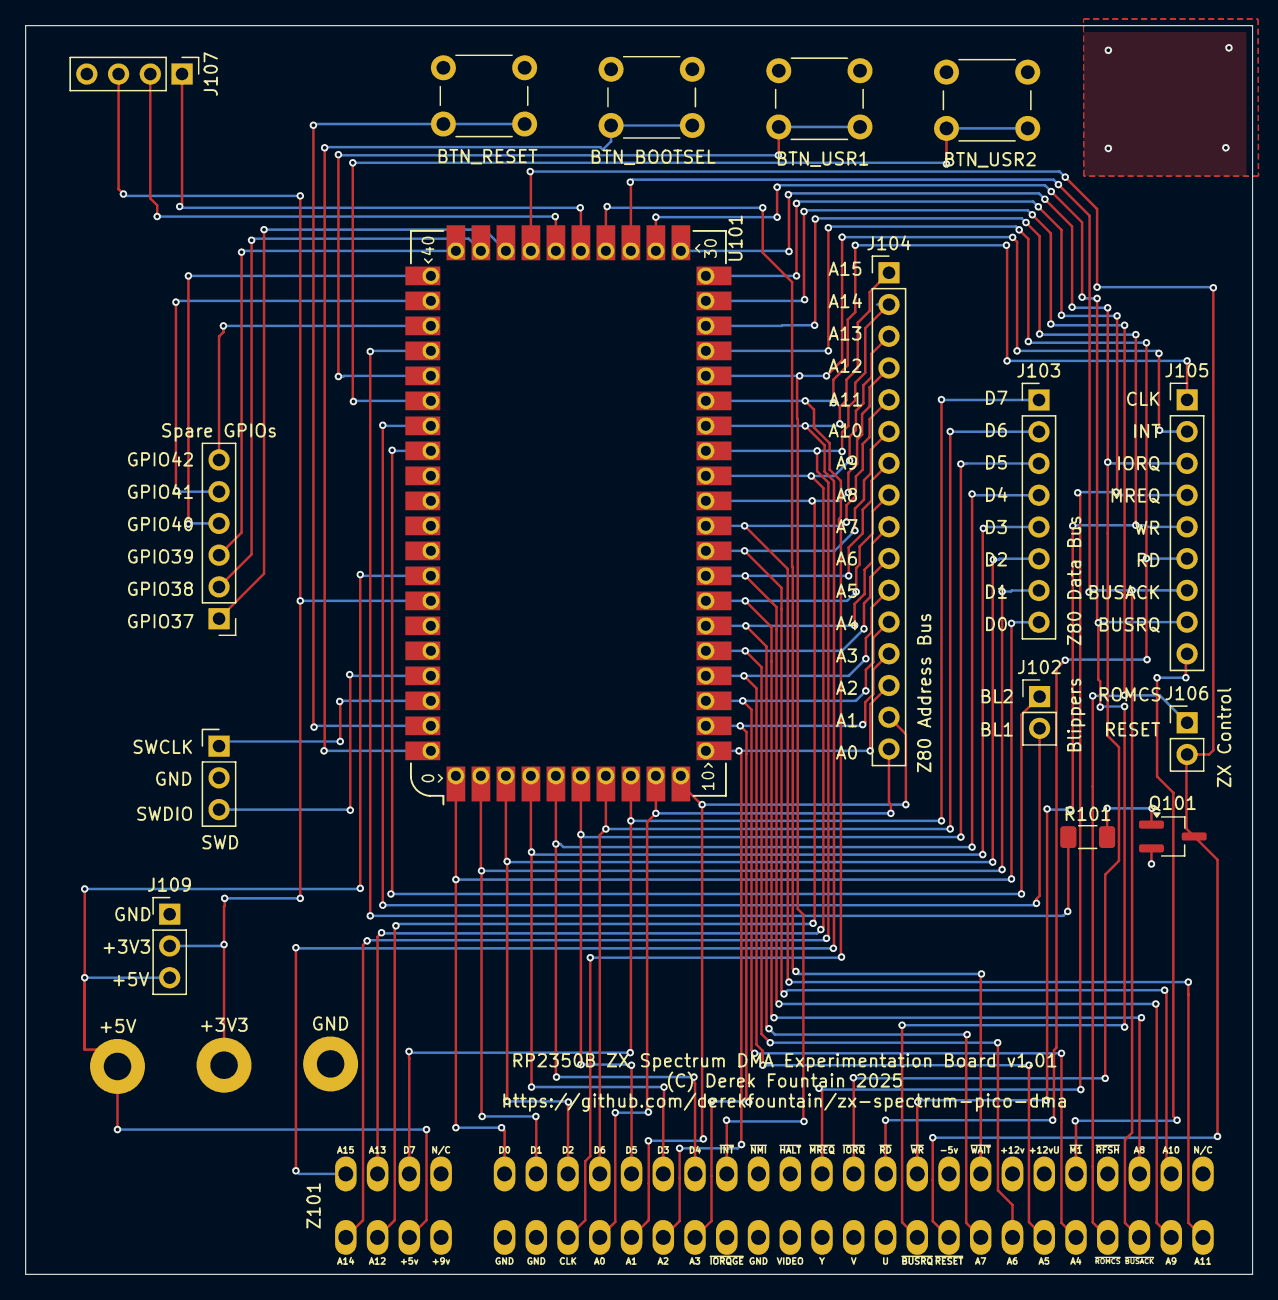
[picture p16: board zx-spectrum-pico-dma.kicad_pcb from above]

Board: 2 copper layers, 98.2 x 99.9 mm, 20 parts (0 on the bottom side), 57 nets.

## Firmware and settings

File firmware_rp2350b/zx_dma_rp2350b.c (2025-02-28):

/*
 * ZX DMA Firmware, a Raspberry Pi RP2350b based Spectrum DMA device
 * Copyright (C) 2025 Derek Fountain
 * 
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
 * You should have received a copy of the GNU General Public License
 * along with this program; if not, write to the Free Software
 * Foundation, Inc., 51 Franklin Street, Fifth Floor, Boston, MA  02110-1301, USA.
 */

/*
 * ZX Spectrum DMA experimentation. Background info at https://worldofspectrum.org/faq/reference/48kreference.htm
 *
 * cmake -DCMAKE_BUILD_TYPE=Debug ..
 * make -j10
 * sudo openocd -f interface/cmsis-dap.cfg -f target/rp2350.cfg -c "program ./zx_dma_rp2350b.elf verify reset exit"
 * sudo openocd -f interface/cmsis-dap.cfg -f target/rp2350.cfg
 * gdb-multiarch ./zx_dma_rp2350b.elf
 *  target remote localhost:3333
 *  load
 *  monitor reset init
 *  continue
 */

#include "pico.h"
#include "pico/stdlib.h"
#include "pico/binary_info.h"
#include "hardware/gpio.h"
#include "hardware/timer.h"
#include "hardware/clocks.h"
#include "pico/multicore.h"

#include "gpios.h"

//#define OVERCLOCK 270000

static void test_blipper( void )
{
  gpio_put( GPIO_BLIPPER1, 1 );
  __asm volatile ("nop");
  __asm volatile ("nop");
  __asm volatile ("nop");
  __asm volatile ("nop");
  gpio_put( GPIO_BLIPPER1, 0 );
}

/*
 * Local copy of the ZX display file. Pixel data is 256x192 pixels,
 * at 8 pixels per byte. Colour attributes are 32x24 bytes
 */
#define ZX_DISPLAY_FILE_PIXEL_SIZE     ((256*192)/8)
#define ZX_DISPLAY_FILE_ATTRIBUTE_SIZE (32*24)
#define ZX_DISPLAY_FILE_SIZE           (ZX_DISPLAY_FILE_PIXEL_SIZE + ZX_DISPLAY_FILE_ATTRIBUTE_SIZE)
static uint8_t zx_screen_mirror[ZX_DISPLAY_FILE_SIZE];

/*
 * This handler is called when the ULA pings the /INT line.
 *
 * Spectrum top border time is 64 line times, which is 14336 T states. That's
 * 0.004096 of a second, or a smidge over 4ms. DMA in top border time needs to
 * run in that time, otherwise contention comes into play, not to mention the Z80
 * potentially writing to screen memory.
 *
 * The top border is 64 lines, each line being 224Ts.
 */
static uint32_t activate_demo = 0;
void int_handler( uint gpio, uint32_t events ) 
{
  /*
   * Crude hack to let the ROM interrupt routine run, makes testing easier
   * because the Spectrum's keyboard scanning routine is in the interrupt
   * routine which runs at the same time as this DMA code.
   * If BASIC isn't running this isn't necessary. Even if BASIC is running
   * the Spectrum still works even without this. So I'm not quite sure how
   * necessary it is.
   */
#define TESTING_FROM_BASIC 0
#if TESTING_FROM_BASIC  
  busy_wait_ms(1);
#endif

  /*
   * Scroll left, just to show something happening. This takes about
   * 465us on an un-overclocked RP2350b
   */
  if( activate_demo > 0 )
  {
    gpio_put( GPIO_BLIPPER2, 1 );

     /* Work down the screen lines */
    for( uint32_t scan_line = 0; scan_line < 192; scan_line++ )
    {
      uint8_t *scan_data = (zx_screen_mirror + (scan_line*32));

      /* Pick up the 0/1 value of the pixel at extreme left */
      uint8_t left_pixel = ((*scan_data & 0x80) == 0x80);

      /* Copy it ready for inserting at extreme right */
      uint8_t right_pixel = left_pixel;

      /* Work across the 32 bytes of the line, right to left */
      for( int32_t char_count = 31; char_count >= 0; char_count-- )
      {
        /*
         * Pick up the byte value, note and store the leftmost pixel 0/1 value
         * (which is about to be scrolled out of this byte)
         */
        uint8_t pixel_byte = *(scan_data+char_count);
        left_pixel = ((pixel_byte & 0x80) == 0x80);

        /*
         * Rotate the value and put the leftmost pixel from the previous byte
         * (the one to this byte's right) into the right side
         */
        pixel_byte = pixel_byte << 1;
        pixel_byte &= 0xFE;
        pixel_byte |= right_pixel;
        
        /*
         * Store that leftmost pixel ready for putting it into the right
         * side of the next byte
         */
        right_pixel = left_pixel;

        /* Load the rotated byte back into the mirror */
        *(scan_data+char_count) = pixel_byte;
      }
    }

    gpio_put( GPIO_BLIPPER2, 0 );
  }

  /* Assert bus request */
  gpio_put( GPIO_Z80_BUSREQ, 0 );

  /*
   * Spin waiting for Z80 to acknowledge. BUSACK goes active (low) on the 
   * rising edge of the clock - see fig8 in the Z80 manual
   */
  while( gpio_get( GPIO_Z80_BUSACK ) == 1 );

  /* OK, we have the Z80's bus */

  /* RD and IORQ lines are unused by this DMA process and stay inactive */
  gpio_set_dir( GPIO_Z80_RD,   GPIO_OUT ); gpio_put( GPIO_Z80_RD,   1 );
  gpio_set_dir( GPIO_Z80_IORQ, GPIO_OUT ); gpio_put( GPIO_Z80_IORQ, 1 );

  /* Reset Z80 address and data bus GPIOs as outputs */
  gpio_set_dir_out_masked( GPIO_ABUS_BITMASK );
  gpio_set_dir_out_masked( GPIO_DBUS_BITMASK );

  /* Set directions of control signals to outputs */
  gpio_set_dir( GPIO_Z80_MREQ, GPIO_OUT ); gpio_put( GPIO_Z80_MREQ, 1 );
  gpio_set_dir( GPIO_Z80_WR,   GPIO_OUT ); gpio_put( GPIO_Z80_WR,   1 );

  /* Blipper goes high while DMA process is active */
  gpio_put( GPIO_BLIPPER1, 1 );

  const uint32_t write_address = 0x4000;

  uint32_t byte_counter;
  for( byte_counter=0; byte_counter < ZX_DISPLAY_FILE_SIZE; byte_counter++ )
  {
    /*
     * A full screen (6,912 byte) DMA transfer (with the static RAM timings
     * below) takes 2.37ms.
     * Top border time is 4.096ms, so DMAing a full screen is easily done
     * inside the time it takes the ULA to draw the top border.
     */

    /* Set address of ZX byte to write to */
    gpio_put_masked( GPIO_ABUS_BITMASK, (write_address+byte_counter)<<GPIO_ABUS_A0 );

    /* Assert memory request */
    gpio_put( GPIO_Z80_MREQ, 0 );

    /* Put value on the data bus */
    gpio_put_masked( GPIO_DBUS_BITMASK, zx_screen_mirror[byte_counter]);

    /*
     * Assert the write line to write it, the ULA responds to this and does
     * the write into the Spectrum's memory. i.e. the RAS/CAS stuff.
     */
    gpio_put( GPIO_Z80_WR, 0 );

    /*
     * Spectrum RAM is rated 150ns which is 1.5e-07. RP2350 clock speed is
     * 150,000,000Hz, so one clock cycle is 6.66666666667e-09. So that's 22.5
     * RP2350 clock cycles in one DRAM transaction time. NOP is T1, so it
     * takes one clock cycle, so 23 NOPs should guarantee a pause long
     * enough for the 4116s to respond.
     */
#define USING_STATIC_RAM_MODULE 1
#if USING_STATIC_RAM_MODULE
  /*
   * This was developed on a Spectrum containing a static RAM-based lower memory
   * module. I thought it would be faster than the 4116s, so should work with
   * fewer than 23 NOPs. Turns out it doesn't. Empirical testing shows it needs 29,
   * which is 1.93e-07 seconds, or about 1.93 microseconds. It don't know why.
   * 
   * Update: it turns out that sometimes 29 is too few and the DMA doesn't work.
   * This appears to be related to the Spectrum's temperature. The cooler the
   * machine is the longer this delay needs to be - but again, this is with a
   * static RAM module.
   * 
   * I've currently got this at 35/150,000,000ths of a second. This seems
   * reliable. A transfer of 6,912 bytes at this speed takes 2.37ms.
   */
    __asm volatile ("nop");
    __asm volatile ("nop");
    __asm volatile ("nop");
    __asm volatile ("nop");
    __asm volatile ("nop");

    __asm volatile ("nop");
    __asm volatile ("nop");
    __asm volatile ("nop");
    __asm volatile ("nop");
    __asm volatile ("nop");

    __asm volatile ("nop");
    __asm volatile ("nop");
    __asm volatile ("nop");
    __asm volatile ("nop");
    __asm volatile ("nop");

    __asm volatile ("nop");
    __asm volatile ("nop");
    __asm volatile ("nop");
    __asm volatile ("nop");
    __asm volatile ("nop");

    __asm volatile ("nop");
    __asm volatile ("nop");
    __asm volatile ("nop");
    __asm volatile ("nop");
    __asm volatile ("nop");

    __asm volatile ("nop");
    __asm volatile ("nop");
    __asm volatile ("nop");
    __asm volatile ("nop");
    __asm volatile ("nop");

    __asm volatile ("nop");
    __asm volatile ("nop");
    __asm volatile ("nop");
    __asm volatile ("nop");
    __asm volatile ("nop");
#else
    /* Timings with 4116s go here */
#endif

    /* Remove write and memory request */
    gpio_put( GPIO_Z80_WR,   1 );
    gpio_put( GPIO_Z80_MREQ, 1 ); 
  }

  /* DMA complete - put the address, data and control buses back to hi-Z */
  gpio_set_dir_in_masked( GPIO_ABUS_BITMASK );
  gpio_set_dir_in_masked( GPIO_DBUS_BITMASK );

  gpio_set_dir( GPIO_Z80_MREQ, GPIO_IN );
  gpio_set_dir( GPIO_Z80_WR,   GPIO_IN );
  gpio_set_dir( GPIO_Z80_IORQ, GPIO_IN );
  gpio_set_dir( GPIO_Z80_RD,   GPIO_IN );

  /* Release bus request */
  gpio_put( GPIO_Z80_BUSREQ, 1 );

  /* Indicate DMA process complete */
  gpio_put( GPIO_BLIPPER1, 0 );

  return;
}

int64_t scroll_display( alarm_id_t id, void *user_data )
{
  /* Set the demo code in the /INT handler running */
  activate_demo = 1;
  return 0;
}

/*
 * Alarm handler, sets the handler for the /INT signal running.
 * That can't start immediately because running the DMA stuff
 * as soon as the Spectrum starts messes up the ROM's memory
 * check as the Spectrum boots.
 */
int64_t start_dma_running( alarm_id_t id, void *user_data )
{
  /*
   * When the ULA pulls /INT low at the start of the frame, dump my
   * mirror of the display file into the Spectrum's live display
   */
  gpio_set_irq_enabled_with_callback( GPIO_Z80_INT, GPIO_IRQ_EDGE_FALL, true, &int_handler );

  /* Demo it's working */
  add_alarm_in_ms( 10000, scroll_display, NULL, 0 );

  return 0;
}

void main( void )
{
  bi_decl(bi_program_description("ZX Spectrum DMA RP2350 Stamp XL Board Binary."));

#ifdef OVERCLOCK
  set_sys_clock_khz( OVERCLOCK, 1 );
#endif

  /* All interrupts off except the timers */
//  irq_set_mask_enabled( 0xFFFFFFFF, 0 );
//  irq_set_mask_enabled( 0x0000000F, 1 );

  /*
   * This is the Z80's /RESET signal, it's an input to this code.
   *
   * The internal pull up is required, but I don't know why. Without it the /RESET
   * line is held low and the Spectrum doesn't start up. With it the /RESET line
   * rises normally and the Spectrum starts as usual. Cutting the track from 
   * /RESET to the GPIO_Z80_RESET GPIO makes the problem go away, so it appears
   * the RP2350 GPIO is where the problem is, it's holding the line low. But I
   * don't really know. I discovered by accident that setting the RP2350's internal
   * pull up makes the problem go away. OK, I'll take it.
   */
  gpio_init( GPIO_Z80_RESET );  gpio_set_dir( GPIO_Z80_RESET, GPIO_IN ); gpio_pull_up( GPIO_Z80_RESET );

  /* GPIO_RESET_Z80 is the output which drives a reset to the Z80. Hold the Z80 in reset until everything is set up */
  gpio_init( GPIO_RESET_Z80 ); gpio_set_dir( GPIO_RESET_Z80, GPIO_OUT ); gpio_put( GPIO_RESET_Z80, 1 );
 
  /* Blippers, for the scope */
  gpio_init( GPIO_BLIPPER1 ); gpio_set_dir( GPIO_BLIPPER1, GPIO_OUT ); gpio_put( GPIO_BLIPPER1, 0 );
  gpio_init( GPIO_BLIPPER2 ); gpio_set_dir( GPIO_BLIPPER2, GPIO_OUT ); gpio_put( GPIO_BLIPPER2, 0 );
 
  /* Not taking over the ZX ROM for the time being */
  gpio_init( GPIO_ROMCS );    gpio_set_dir( GPIO_ROMCS, GPIO_IN );

  /* Set up Z80 control bus */  
  gpio_init( GPIO_Z80_CLK  );   gpio_set_dir( GPIO_Z80_CLK,  GPIO_IN );
  gpio_init( GPIO_Z80_RD   );   gpio_set_dir( GPIO_Z80_RD,   GPIO_IN );
  gpio_init( GPIO_Z80_WR   );   gpio_set_dir( GPIO_Z80_WR,   GPIO_IN );
  gpio_init( GPIO_Z80_MREQ );   gpio_set_dir( GPIO_Z80_MREQ, GPIO_IN );
  gpio_init( GPIO_Z80_IORQ );   gpio_set_dir( GPIO_Z80_IORQ, GPIO_IN );
  gpio_init( GPIO_Z80_INT  );   gpio_set_dir( GPIO_Z80_INT,  GPIO_IN );
  gpio_init( GPIO_Z80_WAIT );   gpio_set_dir( GPIO_Z80_WAIT, GPIO_IN );
 
  gpio_init( GPIO_Z80_BUSREQ ); gpio_set_dir( GPIO_Z80_BUSREQ, GPIO_OUT ); gpio_put( GPIO_Z80_BUSREQ, 1 );
  gpio_init( GPIO_Z80_BUSACK ); gpio_set_dir( GPIO_Z80_BUSACK, GPIO_IN  );

  /* Initialise Z80 data bus GPIOs as inputs */
  gpio_init_mask( GPIO_DBUS_BITMASK );  gpio_set_dir_in_masked( GPIO_DBUS_BITMASK );

  /* Initialise Z80 address bus GPIOs as inputs */
  gpio_init_mask( GPIO_ABUS_BITMASK );  gpio_set_dir_in_masked( GPIO_ABUS_BITMASK );

  /* Zero mirror memory */
  for( uint32_t i=0; i < ZX_DISPLAY_FILE_SIZE; i++)
    zx_screen_mirror[i]=0;

  /* Let the Spectrum run and do its RAM check before we start interferring */
  gpio_put( GPIO_RESET_Z80, 0 );

  /* The DMA stuff starts in a few seconds */
  add_alarm_in_ms( 3000, start_dma_running, NULL, 0 );

  /*
   * The IRQ handler stuff is nowhere near fast enough to handle this. The Z80's
   * write is finished long before the RP2350 even gets to call the handler function.
   * So, tight loop in the main core for now.
   */
  while( 1 )
  {
    register uint64_t gpios = gpio_get_all64();

    /* A memory write is when mem-request and write are both low */
    const uint64_t WR_MREQ_MASK = (0x01 << GPIO_Z80_MREQ) | (0x01 << GPIO_Z80_WR);

    if( (gpios & WR_MREQ_MASK) == 0 )
    {
      /* It's a write to memory, find the address being written to */
      uint64_t address = (gpios & GPIO_ABUS_BITMASK) >> GPIO_ABUS_A0;

      /* For this example I'm only interested in writes to the display file */
      const uint64_t display_first_byte = 0x4000;
      const uint64_t display_last_byte  = 0x5AFF;

      if( (address >= display_first_byte) && (address <= display_last_byte) )
      {
        /* Pick the value being written from the data bus and mirror it */
        uint8_t data = (gpios & GPIO_DBUS_BITMASK) & 0xFF;
        zx_screen_mirror[address-display_first_byte] = data;
      }

      /* Wait for the Z80 write to finish */
      while( (gpio_get_all64() & WR_MREQ_MASK) == 0 );
    }

  }

}

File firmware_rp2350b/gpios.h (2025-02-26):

/*
 * GPIOs for RP2350 Stamp XL
 *
 * These need to match the hardware design.
 */

#ifndef __GPIOS_H
#define GPIOS_H

/* Test signals to scope */
#define GPIO_BLIPPER1     46
#define GPIO_BLIPPER2     47

/* Take over the Spectrum's ROM */
#define GPIO_ROMCS        28

/*
 * This pin is the output connected to the base of Q101.
 * Driving it positive pulls ZXRESET low
 */
#define GPIO_RESET_Z80    43

/*
 * This pin is an input to the RP2350. It's the Z80's
 * /RESET signal and is here so the RP2350 can tell when
 * the Spectrum is being reset. This isn't an output for
 * resetting the Spectrum, GPIO_RESET_Z80 does that.
*/
#define GPIO_Z80_RESET    36

/* Z80 Control bus */
#define GPIO_Z80_CLK      24
#define GPIO_Z80_INT      25
#define GPIO_Z80_RD       26
#define GPIO_Z80_WR       27
#define GPIO_Z80_MREQ     29
#define GPIO_Z80_IORQ     30
#define GPIO_Z80_BUSREQ   31
#define GPIO_Z80_BUSACK   32
#define GPIO_Z80_WAIT     33

/* Z80 Data bus */
#define GPIO_DBUS_D0      0
#define GPIO_DBUS_D1      1
#define GPIO_DBUS_D2      2
#define GPIO_DBUS_D3      3
#define GPIO_DBUS_D4      4
#define GPIO_DBUS_D5      5
#define GPIO_DBUS_D6      6
#define GPIO_DBUS_D7      7

#define GPIO_DBUS_BITMASK 0x000000FF

/* Z80 Address bus */
#define GPIO_ABUS_A0      8
#define GPIO_ABUS_A1      9
#define GPIO_ABUS_A2      10
#define GPIO_ABUS_A3      11
#define GPIO_ABUS_A4      12
#define GPIO_ABUS_A5      13
#define GPIO_ABUS_A6      14
#define GPIO_ABUS_A7      15
#define GPIO_ABUS_A8      16
#define GPIO_ABUS_A9      17
#define GPIO_ABUS_A10     18
#define GPIO_ABUS_A11     19
#define GPIO_ABUS_A12     20
#define GPIO_ABUS_A13     21
#define GPIO_ABUS_A14     22
#define GPIO_ABUS_A15     23

#define GPIO_ABUS_BITMASK 0x00FFFF00

#endif

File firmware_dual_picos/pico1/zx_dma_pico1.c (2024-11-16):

/*
 * ZX DMA Firmware, a Raspberry Pi Pico based Spectrum DMA device
 * Copyright (C) 2024 Derek Fountain
 * 
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
 * You should have received a copy of the GNU General Public License
 * along with this program; if not, write to the Free Software
 * Foundation, Inc., 51 Franklin Street, Fifth Floor, Boston, MA  02110-1301, USA.
 */

/*
 * cmake -DCMAKE_BUILD_TYPE=Debug ..
 * make -j10
 * sudo openocd -f interface/picoprobe.cfg -f target/rp2040.cfg -c "program ./pico1.elf verify reset exit"
 * sudo openocd -f interface/picoprobe.cfg -f target/rp2040.cfg
 * gdb-multiarch ./pico1.elf
 *  target remote localhost:3333
 *  load
 *  monitor reset init
 *  continue
 */

#define _GNU_SOURCE      /* Expose memmem() in string.h */

#include "pico/platform.h"
#include "pico/stdlib.h"
#include "pico/binary_info.h"
#include <string.h>

#include "gpios.h"

static void test_blipper( void )
{
  gpio_put( GPIO_P1_BLIPPER, 1 );
  __asm volatile ("nop");
  __asm volatile ("nop");
  __asm volatile ("nop");
  __asm volatile ("nop");
  gpio_put( GPIO_P1_BLIPPER, 0 );
}

/*
 * https://worldofspectrum.org/faq/reference/48kreference.htm
 *
 * The top border is 64 lines, each line being 224Ts.
 *
 * Spectrum top border time is 64 line times, which is 14336 T states. That's
 * 0.004096 of a second, or a smidge over 4ms. DMA in top border time needs to
 * run in that time, otherwise contention comes into play, not to mention the Z80
 * potentially writing to screen memory.
 *
 * The screen is 192 lines, each line being 224Ts.
 *
 * Lower border is also usable if I can synchronise the Pico to running
 * when the lower border starts. Lower border is 56 lines, which is another
 * 2.229ms, so 6.325ms in total: that's start of lower border to the start of
 * the top line of the display.
 *
 * So, to hit the start of lower border from /INT, I need 64 lines of top border,
 * plus 192 lines of screen, That's 228 lines from /INT to the start of the lower
 * border. At 224Ts per line, 228 lines is 64,512 Ts from /INT to the point I
 * want to start BUSREQ. That's 18.432ms from /INT.
 *
 * The screen is 6144+768 bytes, = 6912 bytes.
 */
int64_t alarm_callback( alarm_id_t id, void *user_data )
{
/* The overlapping interrupts (i.e. INT arriving while the DMA is is running)
 * isn't working. Not sure if the SDK alarm thing is smart enough. Skipping
 * every other INT makes it stable
 */
  static uint32_t  toggle = 0;
  toggle = ~toggle;
  if ( ~toggle )
    return 0;

  /* Assert bus request */
  gpio_put( GPIO_Z80_BUSREQ, 0 );

  /*
   * Spin waiting for Z80 to acknowledge. BUSACK goes active (low) on the 
   * rising edge of the clock - see fig8 in the Z80 manual
   *
   * The delay between BUSREQ being asserted and BUSACK acknowledging is
   * between 800ns and 2uS. Part of that would be the Z80 and whatever it's
   * up to, and part would be how this loop fits with the moment the ACK
   * line goes low.
   */
  while( gpio_get( GPIO_Z80_BUSACK ) == 1 );

  /* RD and IORQ lines are unused and stay inactive */
  gpio_set_dir( GPIO_Z80_RD,   GPIO_OUT ); gpio_put( GPIO_Z80_RD,   1 );
  gpio_set_dir( GPIO_Z80_IORQ, GPIO_OUT ); gpio_put( GPIO_Z80_IORQ, 1 );

  /* Blipper goes high while DMA process is active */
  /* Approx 500ns passes between BUSACK and here */
  gpio_put( GPIO_P1_BLIPPER, 1 );

  uint32_t byte_counter;
  for( byte_counter=0; byte_counter < 6912; byte_counter++ )
  {
    /*
     * Moving on to the right hand side of fig7 in the Z80 manual.
     * We're at the start of T1.
     *
     * Set address bus (active low signal to other Pico), then wait for other
     * Pico to confirm it's done it
     */
    gpio_put( GPIO_P1_REQUEST_SIGNAL, 0 );
    while( gpio_get( GPIO_P2_DRIVING_SIGNAL ) == 1 );

    /*
     * With full Z80 synchronisation a 2048 byte DMA transfer takes 2.9ms.
     * Removing all the Z80 synchronisation stuff and putting in a fairly
     * precise pause tuned to the 150ns DRAM in the Spectrum results in a
     * 2048 byte DMA transfer in 1.850ms.
     * Top border time is 4.096ms, so the target for a 2048 transfer (a
     * third of the screen) is 4.096/3 which is 1.37ms.
     * Using the lower border, 6.325ms/3 is 2.108ms, which I'm now inside.
     *
     * So, use the lower border and my current performance is 5.55ms for
     * the whole screen, which is inside the 6.325 total border time.
     * In theory.
     */

    /* Assert memory request */
    gpio_set_dir( GPIO_Z80_MREQ, GPIO_OUT ); gpio_put( GPIO_Z80_MREQ, 0 );

    /* Put 0x55 on the data bus */
    gpio_set_dir_out_masked( GPIO_DBUS_BITMASK );
    gpio_put_masked( GPIO_DBUS_BITMASK, 0x00000055);

    /* Assert the write line to write it */
    gpio_set_dir( GPIO_Z80_WR, GPIO_OUT ); gpio_put( GPIO_Z80_WR, 0 );

    /*
     * Spectrum RAM is rated 150ns which is 1.5e-07. Pico clock speed is
     * 125,000,000Hz, so one clock cycle is 8e-09. So that's 18.75
     * RP2040 clock cycles in one DRAM transaction time. NOP is T1, so it
     * takes one clock cycle, so 19 NOPs should guarantee a pause long
     * enough for the 4116s to respond.
     */
    __asm volatile ("nop");
    __asm volatile ("nop");
    __asm volatile ("nop");
    __asm volatile ("nop");
    __asm volatile ("nop");

    __asm volatile ("nop");
    __asm volatile ("nop");
    __asm volatile ("nop");
    __asm volatile ("nop");
    __asm volatile ("nop");

    __asm volatile ("nop");
    __asm volatile ("nop");
    __asm volatile ("nop");
    __asm volatile ("nop");
    __asm volatile ("nop");

    __asm volatile ("nop");
    __asm volatile ("nop");
    __asm volatile ("nop");
    __asm volatile ("nop");

    /* Remove write and memory request */
    gpio_put( GPIO_Z80_WR,   1 );
    gpio_put( GPIO_Z80_MREQ, 1 ); 
    
    /*
     * Write cycle is complete. Clean everything up.
     *
     * Remove address bus (active high signal to other Pico).
     */
    gpio_put( GPIO_P1_REQUEST_SIGNAL, 1 );
    while( gpio_get( GPIO_P2_DRIVING_SIGNAL ) == 0 );
  }

  /* Put the data and control buses back to hi-Z */
  gpio_set_dir_in_masked( GPIO_DBUS_BITMASK );

  gpio_set_dir( GPIO_Z80_MREQ, GPIO_IN );
  gpio_set_dir( GPIO_Z80_WR,   GPIO_IN );
  gpio_set_dir( GPIO_Z80_IORQ, GPIO_IN );
  gpio_set_dir( GPIO_Z80_RD,   GPIO_IN );

  /*
   * DMA complete.
   *
   * Release bus request
   */
  gpio_put( GPIO_Z80_BUSREQ, 1 );

  /* Indicate DMA process complete */
  gpio_put( GPIO_P1_BLIPPER, 0 );

  /* Don't reschedule this alarm function */
  return 0;
}
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

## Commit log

2024-11-08 rename LINKOUT pico to pico signal
2024-11-10 change pico1 to work on a hardware interrupt on INT. loop in pico2 to fill top third
2024-11-11 fix bug causing most on screen corruption, there's still something else not quite right
    [gpios.h, zx_dma_pico1.c, zx_dma_pico2.c]
2024-11-12 restore to working single byte DMA after going a bit astray
2024-11-12 putting 256 bytes into the RAM correctly in about 300uS, zx not happy
    [zx_dma_pico1.c, zx_dma_pico2.c]
2024-11-12 2KB transfer takes about 2.25ms, still an intermittent startup problem
    [zx_dma_pico1.c, zx_dma_pico2.c]
2024-11-12 solder wires to expore BUSREQ and BUSACK to pico2. works for 1 byte, not for many
2024-11-13 2 byte DMA working, takes approx 3uS
2024-11-13 2048 byte DMA working, takes approx 3mS which is too slow. top border time is 4ms
    [zx_dma_pico1.c, zx_dma_pico2.c]
2024-11-14 various workings trying to get the WR pause as short as possible
    [zx_dma_pico1.c, zx_dma_pico2.c]
2024-11-16 full screen DMA stable at 25fps
2024-11-19 dual core hack to get the full screen transfer working. which fails, i'll back this out
    [zx_dma_pico1.c]
2024-11-20 start a rp2350b based pcb
    [zx-spectrum-pico-dma.kicad_pcb, zx-spectrum-pico-dma.kicad_sch]
2024-11-21 pull in board from zx diagnostics project
    [zx-spectrum-pico-dma.kicad_pcb, zx-spectrum-pico-dma.kicad_sch]
2024-11-21 add ground area
    [zx-spectrum-pico-dma.kicad_pcb]
2024-11-23 flesh out initial schematic
    [zx-spectrum-pico-dma.kicad_sch]
2024-11-23 more layout work
    [zx-spectrum-pico-dma.kicad_pcb, zx-spectrum-pico-dma.kicad_sch]
2024-11-29 thought about barrel jacks to control zx power, decided against. final tidyups
    [zx-spectrum-pico-dma.kicad_pcb, zx-spectrum-pico-dma.kicad_sch]
2024-11-29 first fabrication
    [zx-spectrum-pico-dma-B_Cu.gbl, zx-spectrum-pico-dma-B_Mask.gbs, zx-spectrum-pico-dma-B_Paste.gbp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]
2024-12-07 finalise and mothball the dual pico code, need to start on RP2350B version
2025-02-13 first draft of rp2350b DMA code
2025-02-23 crude timings, but the DMA is working
2025-02-23 6912 byte DMA now working
2025-02-23 reset GPIO RP2350? workaround in place, firmware is working
    [gpios.h, zx_dma_rp2350b.c]
2025-02-26 update schematic to reflect the revised RESET labelling
    [zx-spectrum-pico-dma.kicad_pcb, zx-spectrum-pico-dma.kicad_sch]
2025-03-01 add photos of the board
2025-03-14 add M1 from edge connector to a pin, it's needed on the logic analyser so I need to make it available
    [zx-spectrum-pico-dma.kicad_pcb, zx-spectrum-pico-dma.kicad_sch]
2025-03-14 add a 3-pin supplies header, the mounting points aren't easy to attach a clip to
    [zx-spectrum-pico-dma.kicad_pcb, zx-spectrum-pico-dma.kicad_sch]

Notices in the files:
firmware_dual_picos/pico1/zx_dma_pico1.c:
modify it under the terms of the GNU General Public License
